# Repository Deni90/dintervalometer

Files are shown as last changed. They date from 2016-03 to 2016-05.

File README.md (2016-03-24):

#Dintervalometer

Intervalometer for DSLR cameras based on Atmega328p and PCD8544 LCD display

##Description

Dintervalometer (Deni's intervalometer) is a custom made intervalometer for DSLR cameras. The main purpose is to enable cameras to shoot time lapses and to allow shutter speed longer than the 30s.

##Features

- Intervalometer
- Bulb mode
- Backlight with variable brightness
- Charging via USB

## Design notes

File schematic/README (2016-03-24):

Schematic and PCB are created with Cadsoft EAGLE

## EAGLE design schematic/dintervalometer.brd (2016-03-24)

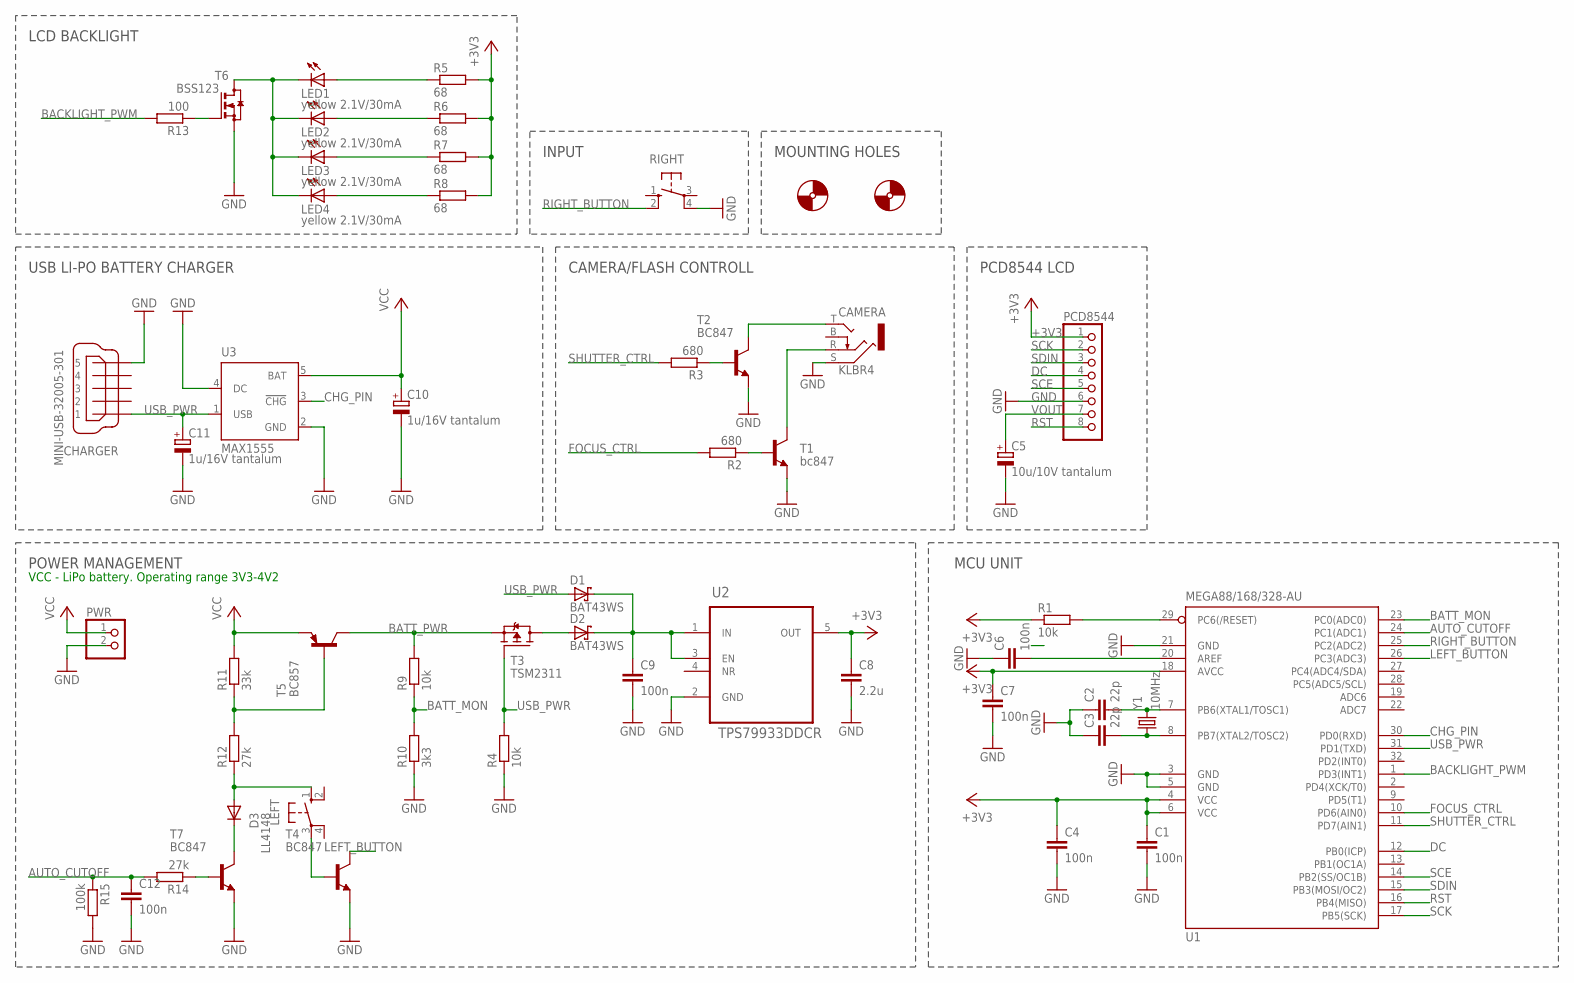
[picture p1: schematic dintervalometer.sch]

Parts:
C1, C4, C6, C7, C9, C12: 100n; C0805
C2, C3: 22p; C0805
C5: 10u/10V tantalum; SMC_A
C8: 2.2u; C0805
C10, C11: 1u/16V tantalum; SMC_A
CAMERA: KLBR4
CHARGER: MINI-USB-32005-301; 32005-301
D1, D2: BAT43WS; SOD323_ST
D3: LL4148; SOD80C
LED1, LED2, LED3, LED4: yellow 2.1V/30mA; CHIP-LED0805
LEFT: 10-XX; B3F-10XX
PCD8544: PINHD-1X8; 1X08
PWR: PINHD-1X2/90; 1X02/90
R1, R4, R9: 10k; M0805
R2, R3: 680; M0805
R5, R6, R7, R8: 68; M0805
R10: 3k3; M0805
R11: 33k; M0805
R12, R14: 27k; M0805
R13: 100; M0805
R15: 100k; M0805
RIGHT: 10-XX; B3F-10XX; MPN B3F-1000
T1: bc847; SOT23-BEC
T2: BC847; SOT23-BEC
T3: TSM2311; SOT23
T4, T7: BC847; SOT23
T5: BC857; SOT23-BEC
T6: BSS123; SOT23
U1: MEGA88/168/328-AU; TQFP32-08
U2: TPS79933DDCR; SOT95P290X145-5N
U3: MAX1555; SOT23-5L
X1, X3: 2.8MM_HOLE
Y1: 10MHz; 5X3.2MM

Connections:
+3V3: C1.1, C4.1, C7.1, C8.1, PCD8544.1, R1.1, R5.2, R6.2, R7.2, R8.2, U1.4 (VCC), U1.6 (VCC), U1.18 (AVCC), U2.5 (OUT)
AUTO_CUTOFF: C12.1, R14.2, R15.1, U1.24 (PC1(ADC1))
BACKLIGHT_PWM: R13.2, U1.1 (PD3(INT1))
BATT_MON: R9.1, R10.2, U1.23 (PC0(ADC0))
BATT_PWR: R9.2, T3.2 (S), T5.C
CHG_PIN: U1.30 (PD0(RXD)), U3.3 (!CHG)
DC: PCD8544.4, U1.12 (PB0(ICP))
FOCUS_CTRL: R2.2, U1.10 (PD6(AIN0))
GND: C1.2, C2.1, C3.1, C4.2, C5.-, C6.1, C7.2, C8.2, C9.2, C10.-, C11.-, C12.2, CAMERA.S, CHARGER.5, PCD8544.6, PWR.2, R4.1, R10.1, R15.2, RIGHT.4 (P1), T1.E, T2.E, T4.2 (E), T6.2 (S), T7.2 (E), U1.3 (GND), U1.5 (GND), U1.21 (GND), U2.2 (GND), U3.2 (GND), U3.4 (DC)
LEFT_BUTTON: T4.3 (C), U1.26 (PC3(ADC3))
unnamed: R1.2, U1.29 (PC6(/RESET))
unnamed: C2.2, U1.7 (PB6(XTAL1/TOSC1)), Y1.3 (2)
unnamed: C3.2, U1.8 (PB7(XTAL2/TOSC2)), Y1.1
unnamed: R3.1, T2.B
unnamed: R11.1, R12.2, T5.B
unnamed: C6.2, U1.20 (AREF)
unnamed: LED1.A, R5.1
unnamed: D3.A, LEFT.1 (S), R12.1
unnamed: D3.C, T7.3 (C)
unnamed: D2.A, T3.3 (D)
unnamed: LEFT.3, T4.1 (B)
unnamed: LED1.C, LED2.C, LED3.C, LED4.C, T6.3 (D)
unnamed: R2.1, T1.B
unnamed: R13.1, T6.1 (G)
unnamed: LED2.A, R6.1
unnamed: LED3.A, R7.1
unnamed: LED4.A, R8.1
unnamed: CAMERA.T, T2.C
unnamed: CAMERA.R, T1.C
unnamed: R14.1, T7.1 (B)
unnamed: C9.1, D1.C, D2.C, U2.1 (IN), U2.3 (EN)
RIGHT_BUTTON: RIGHT.2 (S1), U1.25 (PC2(ADC2))
RST: PCD8544.8, U1.16 (PB4(MISO))
SCE: PCD8544.5, U1.14 (PB2(SS/OC1B))
SCK: PCD8544.2, U1.17 (PB5(SCK))
SDIN: PCD8544.3, U1.15 (PB3(MOSI/OC2))
SHUTTER_CTRL: R3.2, U1.11 (PD7(AIN1))
USB_PWR: C11.+, CHARGER.1, D1.A, R4.2, T3.1 (G), U1.31 (PD1(TXD)), U3.1 (USB)
VCC: C10.+, PWR.1, R11.2, T5.E, U3.5 (BAT)
VOUT: C5.+, PCD8544.7

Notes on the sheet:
VCC - LiPo battery. Operating range 3V3-4V2
USB LI-PO BATTERY CHARGER
LCD BACKLIGHT
CAMERA/FLASH CONTROLL
PCD8544 LCD
MOUNTING HOLES
POWER MANAGEMENT
MCU UNIT
INPUT

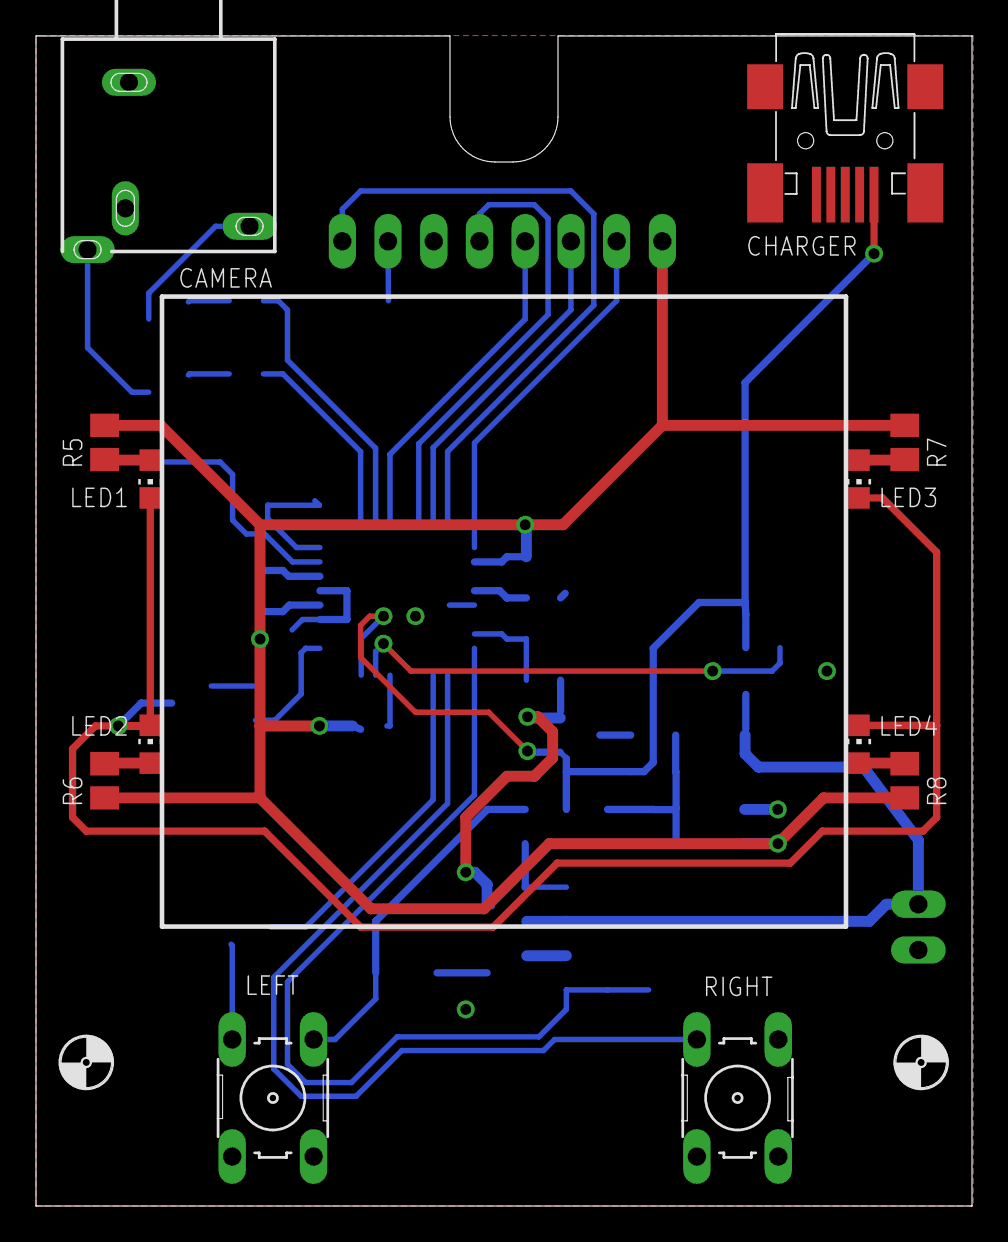
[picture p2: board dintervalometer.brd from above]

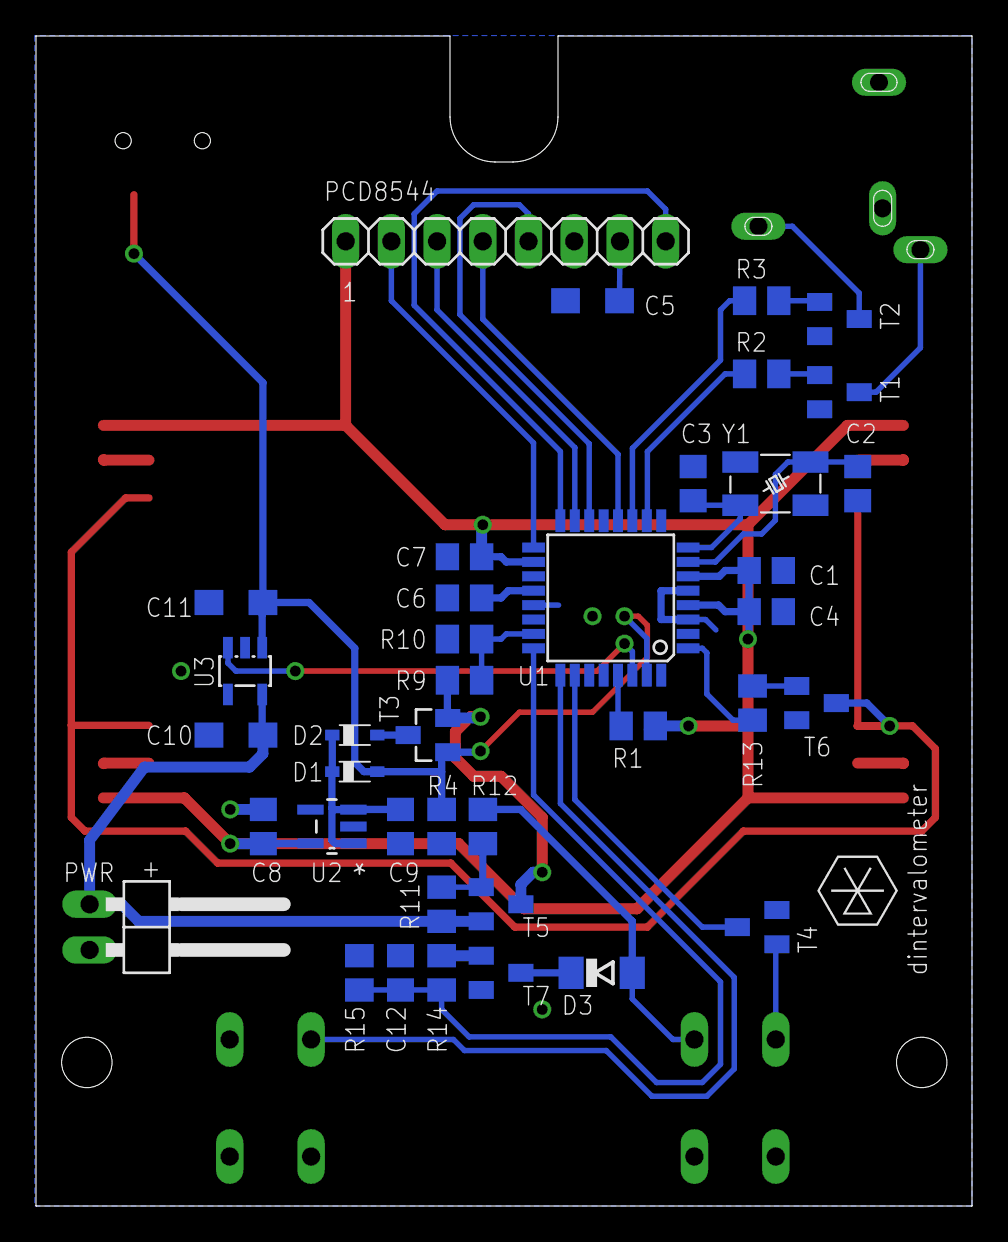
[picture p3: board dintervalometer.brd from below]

Board: 2 copper layers, 52.0 x 65.0 mm, 53 parts (39 on the bottom side), 40 nets.

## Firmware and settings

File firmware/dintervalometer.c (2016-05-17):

/*
 *  dintervalometer.c
 *
 *  "THE DON'T-CARE LICENCE"
 *  I don't care, do whatever you want with this file.
 *
 *  Author: Daniel Knezevic
 *  E-mail: danielknezevic90<at>gmail.com
 */

#include <avr/io.h>
#include <avr/interrupt.h>
#include <avr/eeprom.h>
#include <math.h>

#include "dintervalometer.h"
#include "pcd8544.h"

// String constants and icons stored in flash
const __flash char turn_on_message_str[]
= "Hold buttons for 2s\n     to turn on\n";
const __flash char main_menu_title_str[] = "MAIN MENU\n";
const __flash char intervalometer_menu_title_str[] = "INTERVALOMETER\n";
const __flash char bulb_mode_menu_title_str[] = "BULB MODE\n";
const __flash char settings_menu_title_str[] = "SETTINGS\n";
const __flash char intervalometer_option_str[] = " Intervalometer\n";
const __flash char bulb_mode_option_str[] = " Bulb mode\n";
const __flash char settings_option_str[] = " Settings\n";
const __flash char turn_off_option_str[] = " Turn off\n";
const __flash char delay_str[] = " delay  ";
const __flash char interval_str[] = " period ";
const __flash char shots_str[] = " shots       ";
const __flash char prefocus_str[] = " prefocus    ";
const __flash char start_str[] = " start";
const __flash char duration_str[] = " bulb   ";
const __flash char on_str[] = " on";
const __flash char off_str[] = "off";
const __flash char done_str[] = "Done";
const __flash char help_bar_1_str[] = "down/set        up";
const __flash char help_bar_2_str[] = "down/set  up/back";
const __flash char help_bar_3_str[] = "++/set       --/set";
const __flash char abort_str[] = "/abort";
const __flash char back_str[] = "/back";
const __flash char cleanup_message_str[] = "    Turning off\n    bye, bye :)\n";
const __flash char backlight_str[] = " backlight    ";
const __flash char auto_cutoff_str[] = " auto cutoff ";
const __flash char low_battery_str[] = "Low battery!";
const __flash char charging_str[] = "Charging";
const __flash char full_battery_str[] = "Battery is full";

const __flash char clock_icon[] = {0x00, 0x18, 0x24, 0x42, 0x5e, 0x52, 0x24, 0x18};
const __flash char bulb_icon[] = {0x00, 0x00, 0x02, 0x2d, 0x69, 0x2d, 0x02,
    0x00};
const __flash char settings_icon[] = {0x00, 0x18, 0x18, 0x18, 0x18, 0x3c, 0x24,
    0x24};
const __flash char turn_off_icon[] = {0x00, 0x18, 0x24, 0x40, 0x4e, 0x40, 0x24,
    0x18};
const __flash char delay_icon[] = {0x00, 0x41, 0x63, 0x75, 0x6d, 0x75, 0x63,
    0x41};
const __flash char focus_icon[] = {0x00, 0x63, 0x41, 0x1c, 0x14, 0x1c, 0x41,
    0x63};
const __flash char image_icon[] = {0x00, 0x7f, 0x41, 0x41, 0x4f, 0x49, 0x4a,
    0x7c};
const __flash char start_icon[] = {0x00, 0x00, 0x7f, 0x7f, 0x3e, 0x1c, 0x08,
    0x00};
const __flash char battery_icon_elements[] = {0x1c, 0x63, 0x41, 0x7f};
const __flash char image_icon_top[] = {0x00, 0x00, 0x00, 0x00, 0xfe, 0x02, 0x02,
    0x02, 0x02, 0x7e, 0x42, 0x44, 0x48, 0x50, 0xe0, 0x00, 0x00, 0x00,
    0x00};
const __flash char image_icon_bottom[] = {0x00, 0x00, 0x00, 0x00, 0x3f, 0x20,
    0x20, 0x20, 0x20, 0x20, 0x20, 0x20, 0x20, 0x20, 0x3f, 0x00, 0x00, 0x00,
    0x00};
const __flash char delay_icon_top[] = {0x00, 0x00, 0x00, 0x02, 0x06, 0x0A,
    0x12, 0x62, 0xE2, 0xE2, 0xE2, 0x62, 0x12, 0x0A, 0x06, 0x02, 0x00, 0x00,
    0x00};
const __flash char delay_icon_bottom[] = {0x00, 0x00, 0x00, 0x40, 0x60, 0x70,
    0x78, 0x76, 0x71, 0x73, 0x71, 0x76, 0x78, 0x70, 0x60, 0x40, 0x00, 0x00,
    0x00};
const __flash char bulb_icon_top[] = {0x00, 0x00, 0x00, 0x00, 0x38, 0x44, 0x82,
    0x02, 0x32, 0xD2, 0x32, 0x02, 0x82, 0x44, 0x38, 0x00, 0x00, 0x00, 0x00};
const __flash char bulb_icon_bottom[] = {0x00, 0x00, 0x00, 0x00, 0x00, 0x00,
    0x01, 0x0E, 0x38, 0x7F, 0x38, 0x0E, 0x01, 0x00, 0x00, 0x00, 0x00, 0x00,
    0x00};
const __flash char battery_icon[] = {0x1c, 0x36, 0x22, 0x22, 0x22, 0x3e, 0x3e,
    0x3e};
const __flash char battery_tray_icon[] = {0x0e, 0x1f, 0x11, 0x11, 0x11, 0x11, 0x11,
    0x11, 0x11, 0x11, 0x11, 0x11, 0x1f};
const __flash char backlight_icon[] = {0x08, 0x2a, 0x1c, 0x7f, 0x1c, 0x2a, 0x08,
    0x00};

// RAM varibles used for measuring/counting time for various actions
volatile unsigned int clock;                    // used for global timer
volatile unsigned int blink_timer = 0;         //used for blinking in menus
volatile unsigned int button_hold_timer = 0;  // counter for press/hold decision
volatile unsigned int unlock_timer = 0;         // timer to unlock the device
volatile unsigned int timeout_timer = 0; // timer to turn off the device on startup when there is no input from the user
volatile unsigned int delay_timer = 0; // used for interrupt based delay function
volatile unsigned int debounce_timer = 0;       // used for button debunce
volatile unsigned int backlight_timer = 0; // backlight is on until the value reaches 0
volatile unsigned int battery_check_timer = 0;  // timer for battery management

// RAM variables used to store information related to states of the buttons
volatile uint8_t button_press = 0x00;
volatile uint8_t button_hold = 0x00;
volatile uint8_t last_button_state = 0x00;

// Settings with initial values stored in eeprom
settings_t EEMEM settings_data_backup = { 0, MIN_BATTERY_VOLTAGE };

// Global variables
state_t cur_state = INIT;
uint8_t selected_menu_item = 0;
uint8_t is_prop_selected = 0;
uint8_t is_blinking = 0;
intervalometer_t intervalometer_data = { 0, 0, 0, 0 };
intervalometer_t intervalometer_temp_data = { 0, 0, 0, 0 };
uint8_t intervalometer_pre_start = FALSE;
uint16_t remaining_time = 0; // seconds
uint8_t update_image_icon = 0;
bulb_mode_t bulb_mode_data = { 0, 0 };
bulb_mode_t bulb_mode_temp_data = { 0, 0 };
uint8_t bulb_mode_pre_start = FALSE;
uint8_t number_part = 0;
settings_t settings_data;
uint16_t battery_voltage = 0;

// State functions
state_t STATE_init(void);
state_t STATE_main_menu(void);
state_t STATE_intervalometer_menu(void);
state_t STATE_bulb_mode_menu(void);
state_t STATE_settings_menu(void);
state_t STATE_intervalometer(void);
state_t STATE_bulb_mode(void);
state_t STATE_turn_off(void);

// state functions must be in same order as states in state_t enum (look in dintervalometer.h)
state_func_t* const state_table[NUM_OF_STATES] = { STATE_main_menu,
        STATE_intervalometer_menu, STATE_bulb_mode_menu, STATE_settings_menu,
        STATE_turn_off, STATE_intervalometer, STATE_bulb_mode, STATE_init };

state_t STATE_run_state(state_t cur_state) {
    return state_table[cur_state]();
}

// Misc
/*
 * Initializes timer1
 */
void TIMER_init(void);

/*
 * Interrupt based delay function 1-65536ms (65sec max)
 */
void TIMER_delay_ms(uint16_t _mS);

/*
 * Initializes ADC on ADC0(PC0) for battery voltage monitoring
 */
void BATTERY_init_adc(void);

/*
 * Reads battery voltage by using ADC.
 * return value: measured value in mV
 */
uint16_t BATTERY_read_voltage(void);

/*
 * Periodically measures battery voltage and if the voltage is under the
 * margin notifies the user with some message and turns off the device
 */
void BATTERY_monitor(void);

/*
 * Initializes timer2 for PWM on OC2B(PD3), PWM frewuency should be few kHz
 */
void BACKLIGHT_init_pwm(void);

/*
 * Updates backlight status. It will be turned on if brightness > 0
 */
void BACKLIGHT_update(uint8_t brightness);

/*
 * Basic GPIO initialization
 */
void GPIO_init(void);

/*
 * Prints hh:mm:ss time format from seconds
 */
void LCD_print_time(uint16_t _value, uint8_t size);

/*
 * Draws a scroll bar on LCD based on number of items and on currently
 * selected item
 */
void LCD_update_scroll_bar(uint8_t selected_item, uint8_t total_items);

/*
 * Draws a battery icon on top right corner of the LCD based on the measured
 * battery voltage
 */
void LCD_update_battery_icon(uint16_t voltage);

/*
 * Shows low battery notification
 */
void LCD_show_low_battery_alert(void);

/*
 * Timer1 "Compare Match" ISR
 */
ISR(TIMER1_COMPA_vect, ISR_NOBLOCK) {
    clock++;
    blink_timer++;
    delay_timer++;
    debounce_timer++;
    battery_check_timer++;
    if (button_hold_timer)
        button_hold_timer--;   // to detect button holds, we shouldn't overflow!
    if (unlock_timer)
        unlock_timer--;         // to unlock the device, we shouldn't overflow!
    if (timeout_timer)
        timeout_timer--;       // to turn off the device, we shouldn't overflow!
    if (backlight_timer)
        backlight_timer--;
    else
        OCR2B = 0; // turn off the backlight
}

/*
 * Interrupt based button sensing
 * Code borrowed and modified from:
 * http://www.elektronika.ba/789/reverse-geocaching-geogame-v1/
 */
ISR(PCINT1_vect, ISR_NOBLOCK) {
    PCICR &= ~(1 << PCIE1);     // ..disable interrupts for the entire section

    /* up/set button handling part */
    if (!(LEFT_BUTTON_PIN & (1 << LEFT_BUTTON_IO))) {   // if is button pressed
        // see if it wasn't pressed at all
        if (!(last_button_state & (1 << LEFT_BUTTON_IO))) {
            TIMER_delay_ms(DEBOUNCE_INTERVAL);                       // debounce
            // if it is still not VCC after DEBOUNCE_INTERVAL, this was an error
            if ((LEFT_BUTTON_PIN & (1 << LEFT_BUTTON_IO))) {
                PCICR |= (1 << PCIE1); // ..re-enable interrupts for the entire section
                return;
            }
            last_button_state |= (1 << LEFT_BUTTON_IO);
            button_hold_timer = BUTTON_HOLD_INTERVAL; // load for hold detection
            while (button_hold_timer > 0) {
                // if button released in meantime
                if ((LEFT_BUTTON_PIN & (1 << LEFT_BUTTON_IO))) {
                    button_press = (1 << LEFT_BUTTON_IO); // this was just a press!
                    PCICR |= (1 << PCIE1); // ..re-enable interrupts for the entire section
                    return;
                }
            }
            // if we get to this line, the button is still pressed, so "it is held"
            button_hold = (1 << LEFT_BUTTON_IO);
        }
    } else {
        last_button_state &= ~(1 << LEFT_BUTTON_IO);
    }

    /* down/back button handling part */
    if (!(RIGHT_BUTTON_PIN & (1 << RIGHT_BUTTON_IO))) { // if button is pressed
        // see if it wasn't pressed at all
        if (!(last_button_state & (1 << RIGHT_BUTTON_IO))) {
            TIMER_delay_ms(DEBOUNCE_INTERVAL);                       // debounce
            // if it is still not VCC after DEBOUNCE_INTERVAL, this was an error
            if ((RIGHT_BUTTON_PIN & (1 << RIGHT_BUTTON_IO))) {
                PCICR |= (1 << PCIE1); // ..re-enable interrupts for the entire section
                return;
            }
            last_button_state |= (1 << RIGHT_BUTTON_IO);
            button_hold_timer = BUTTON_HOLD_INTERVAL; // load for hold detection
            while (button_hold_timer > 0) {
                // if button released in meantime
                if ((RIGHT_BUTTON_PIN & (1 << RIGHT_BUTTON_IO))) {
                    button_press = (1 << RIGHT_BUTTON_IO); // this was just a press!
                    PCICR |= (1 << PCIE1); // ..re-enable interrupts for the entire section
                    return;
                }
            }
            // if we get to this line, the button is still pressed, so "it is held"
            button_hold = (1 << RIGHT_BUTTON_IO);
        }
    } else {
        last_button_state &= ~(1 << RIGHT_BUTTON_IO);
    }

    PCICR |= (1 << PCIE1);  // ..re-enable interrupts for the entire section
}

int main(void) {
    TIMER_init();
    BATTERY_init_adc();
    BACKLIGHT_init_pwm();
    GPIO_init();
    // Enable Global Interrupts
    sei();
    LCD_init();

    // restore settings from eeprom
    eeprom_read_block(&settings_data, &settings_data_backup,
            sizeof(settings_t));

    while (1) {
        cur_state = STATE_run_state(cur_state);   //start the state machine
    }   // while
    return 0;
}

state_t STATE_init(void) {
    state_t next_state = cur_state;
    PCICR &= ~(1 << PCIE1); // Disable PIN Change Interrupt 1 - This disables interrupts on pins PCINT14...8 see p73 of datasheet

    BACKLIGHT_update(settings_data.backlight_intensity);

    LCD_clear();

    // First check are the device powered with USB (Charging the battery)
    if (USB_PWR_PIN & (1 << USB_PWR_IO)) {
        if (CHG_PIN & (1 << CHG_IO)) {
            // charging in progress
            LCD_goto(25, 2);
            LCD_puts(charging_str, LCD_TYP_NORM);
        }
        // block until the battery is full -> CHG = 0
        while (CHG_PIN & (1 << CHG_IO))
            ;
        // battery is full
        LCD_clear();
        LCD_goto(12, 2);
        LCD_puts(full_battery_str, LCD_TYP_NORM);

    }
    // block until the USB is connected
    while (USB_PWR_PIN & (1 << USB_PWR_IO))
        ;

    battery_voltage = BATTERY_read_voltage();
    if (battery_voltage < settings_data.battery_auto_cutoff) {
        LCD_show_low_battery_alert();
        STATE_turn_off();
    }
    LCD_update_battery_icon(battery_voltage);
    LCD_goto(0, 2);
    // show help message to turn on the device
    LCD_puts(turn_on_message_str, LCD_TYP_NORM);
    timeout_timer = TIMEOUT_INTERVAL;   // start timer
    AUTO_CUTOFF_PORT |= (1 << AUTO_CUTOFF_IO);  // pull up the port

    while (1) {
        // if it reaches timeout turn off the device
        if (timeout_timer == 0) {
            next_state = OFF;
            break;
        }
        // check the buttons. If the buttons are held until the UNLOCK_INTERVAL unlock the device.
        if (!(LEFT_BUTTON_PIN & (1 << LEFT_BUTTON_IO))
                && !(RIGHT_BUTTON_PIN & (1 << RIGHT_BUTTON_IO))) {
            TIMER_delay_ms(DEBOUNCE_INTERVAL);    // debounce
            // if some of the buttons are released in the meantime, turn off the device
            if ((LEFT_BUTTON_PIN & (1 << LEFT_BUTTON_IO))
                    || (RIGHT_BUTTON_PIN & (1 << RIGHT_BUTTON_IO))) {
                next_state = OFF;
                break;
            }
            last_button_state |= (1 << LEFT_BUTTON_IO) | (1 << RIGHT_BUTTON_IO);
            uint8_t i;
            // Show initial progress bar and battery icon
            LCD_clear();
            LCD_update_battery_icon(battery_voltage);
            LCD_goto(10, 2);
            for (i = 0; i < 64; i++) {
                if (i == 0 || i == 63)
                    LCD_writeData(0xff);
                else
                    LCD_writeData(0x81);
            }
            // prepare for successful unlock
            next_state = MAIN_MENU;
            selected_menu_item = 0;
            // start unlock_timer
            unlock_timer = UNLOCK_INTERVAL;
            while (unlock_timer > 0) {
                // Update progress bar
                LCD_goto(10, 2);
                for (i = 0; i < 64; i++) {
                    if (i < 64 - unlock_timer / 31 || i == 63)
                        LCD_writeData(0xff);
                    else
                        LCD_writeData(0x81);
                }
                // check if the buttons are released in the meantime, if yes turn off the device
                if ((LEFT_BUTTON_PIN & (1 << LEFT_BUTTON_IO))
                        || (RIGHT_BUTTON_PIN & (1 << RIGHT_BUTTON_IO))) {
                    last_button_state &= ~(1 << LEFT_BUTTON_IO)
                            & ~(1 << RIGHT_BUTTON_IO);
                    next_state = OFF;
                    break;
                }
            }
            break;
        }
    }
    return next_state;
}

state_t STATE_main_menu(void) {
    uint8_t menu_size;
    state_t next_state = cur_state;
    PCICR &= ~(1 << PCIE1); // Disable PIN Change Interrupt 1 - This disables Interrupt 1 - This enables interrupts on pins PCINT14...8 see p73 of datasheet
    // main menu
    LCD_clear();
    LCD_update_battery_icon(battery_voltage);
    menu_size = 4;
    // menu title
    LCD_puts(main_menu_title_str, LCD_TYP_UP2);
    // intervalometer menu item (icon + name)
    LCD_putCustomChar(clock_icon, ICON_WIDTH,
            (selected_menu_item == 0) ? LCD_TYP_INV : LCD_TYP_NORM);
    LCD_puts(intervalometer_option_str,
            (selected_menu_item == 0) ? LCD_TYP_INV : LCD_TYP_NORM);
    // bulb mode menu item  (icon + name)
    LCD_putCustomChar(bulb_icon, ICON_WIDTH,
            (selected_menu_item == 1) ? LCD_TYP_INV : LCD_TYP_NORM);
    LCD_puts(bulb_mode_option_str,
            (selected_menu_item == 1) ? LCD_TYP_INV : LCD_TYP_NORM);
    // settings menu item  (icon + name)
    LCD_putCustomChar(settings_icon, ICON_WIDTH,
            (selected_menu_item == 2) ? LCD_TYP_INV : LCD_TYP_NORM);
    LCD_puts(settings_option_str,
            (selected_menu_item == 2) ? LCD_TYP_INV : LCD_TYP_NORM);
    LCD_putCustomChar(turn_off_icon, ICON_WIDTH,
            (selected_menu_item == 3) ? LCD_TYP_INV : LCD_TYP_NORM);
    LCD_puts(turn_off_option_str,
            (selected_menu_item == 3) ? LCD_TYP_INV : LCD_TYP_NORM);
    // help bar on the bottom
    LCD_goto(0, 5);
    LCD_puts(help_bar_1_str, LCD_TYP_NORM);
    // draw scroll bar
    LCD_update_scroll_bar(selected_menu_item, menu_size);

    PCICR |= (1 << PCIE1); // Enable PIN Change Interrupt 1 - This enables interrupts on pins PCINT14...8 see p73 of datasheet
    // wait button press or hold
    while (!(button_press | button_hold)) {
        // periodically check the battery status
        BATTERY_monitor();
    }

    // turn on the backlight (if enabled) when some button is pressed/held
    BACKLIGHT_update(settings_data.backlight_intensity);

    if (button_press & (1 << LEFT_BUTTON_IO)) {
        button_press &= ~(1 << LEFT_BUTTON_IO); // button press handled
        button_hold &= ~(1 << LEFT_BUTTON_IO); // also clear the hold flag if any...
        selected_menu_item++;
        selected_menu_item %= menu_size;
    } else if (button_press & (1 << RIGHT_BUTTON_IO)) {
        button_press &= ~(1 << RIGHT_BUTTON_IO); // button press handled
        button_hold &= ~(1 << RIGHT_BUTTON_IO); // also clear the hold flag if any...
        if (selected_menu_item)
            selected_menu_item--;
        else
            selected_menu_item = menu_size - 1;
    } else if (button_hold & (1 << LEFT_BUTTON_IO)) {
        button_hold &= ~(1 << LEFT_BUTTON_IO);  // button hold handled
        button_press &= ~(1 << LEFT_BUTTON_IO); // also clear the press flag if any...
        next_state = selected_menu_item + 1; // next state is a selected submenu item
        selected_menu_item = 0;
    } else if ((button_press & (1 << RIGHT_BUTTON_IO))
            || (button_hold & (1 << RIGHT_BUTTON_IO))) {
        // clear the press/hold flag
        button_hold &= ~(1 << RIGHT_BUTTON_IO);
        button_press &= ~(1 << RIGHT_BUTTON_IO);
    }
    return next_state;
}
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

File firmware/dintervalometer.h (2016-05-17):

/*
 *  dintervalometer.h
 *
 *  "THE DON'T-CARE LICENCE"
 *  I don't care, do whatever you want with this file.
 *
 *  Author: Daniel Knezevic
 *  E-mail: danielknezevic90<at>gmail.com
 */

#ifndef DINTERVALOMETER_H_
#define DINTERVALOMETER_H_

#define TRUE                    1
#define FALSE                   0

#define ONE_SECOND              1000    // milliseconds

#define BUTTON_HOLD_INTERVAL    1000    // miliseconds to pronounce button as held rather than pressed
#define UNLOCK_INTERVAL         2000    // milliseconds
#define TIMEOUT_INTERVAL        2000    // milliseconds
#define DEBOUNCE_INTERVAL       50      // milliseconds

#define LEFT_BUTTON_DDR         DDRC
#define LEFT_BUTTON_PIN         PINC
#define LEFT_BUTTON_PORT        PORTC
#define LEFT_BUTTON_IO          PC3

#define RIGHT_BUTTON_DDR        DDRC
#define RIGHT_BUTTON_PIN        PINC
#define RIGHT_BUTTON_PORT       PORTC
#define RIGHT_BUTTON_IO         PC2

#define AUTO_CUTOFF_DDR         DDRC
#define AUTO_CUTOFF_PIN         PINC
#define AUTO_CUTOFF_PORT        PORTC
#define AUTO_CUTOFF_IO          PC1

#define SHUTTER_DDR             DDRD
#define SHUTTER_PIN             PIND
#define SHUTTER_PORT            PORTD
#define SHUTTER_IO              PD7

#define FOCUS_DDR               DDRD
#define FOCUS_PIN               PIND
#define FOCUS_PORT              PORTD
#define FOCUS_IO                PD6

#define CHG_DDR                 DDRD
#define CHG_PIN                 PIND
#define CHG_PORT                PORTD
#define CHG_IO                  PD0

#define USB_PWR_DDR             DDRD
#define USB_PWR_PIN             PIND
#define USB_PWR_PORT            PORTD
#define USB_PWR_IO              PD1

#define BACKLIGHT_DDR           DDRD
#define BACKLIGHT_PIN           PIND
#define BACKLIGHT_PORT          PORTD
#define BACKLIGHT_IO            PD3
#define BACKLIGHT_DURATION      10000   // millisecond

#define BLINK_PERIOD           1000     // millisecons
#define ICON_WIDTH              8

#define MAX_BATTERY_VOLTAGE     4200    // mV
#define MIN_BATTERY_VOLTAGE     3600    // mV
#define BATTERY_MONITOR_PERIOD  60000   // milliseconds

#define PN_JUNCTION             600     // mV

#define BACKLIGHT_INTENSITY     63

typedef enum state_e {
    MAIN_MENU = 0,
    INTERVALOMETER_MENU,
    BULB_MODE_MENU,
    SETTINGS,
    OFF,
    INTERVALOMETER,
    BULB_MODE,
    INIT,
    NUM_OF_STATES
} state_t;

typedef state_t state_func_t(void);

typedef struct intervalometer_s {
    uint16_t delay;
    uint16_t period;
    uint16_t shots;
    uint8_t prefocus;
} intervalometer_t;

typedef struct bulb_mode_s {
    uint16_t delay;
    uint16_t duration;
} bulb_mode_t;

typedef struct settings_s {
    uint8_t backlight_intensity;
    uint16_t battery_auto_cutoff;   //mV
} settings_t;

#endif /* DINTERVALOMETER_H_ */

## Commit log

2016-03-31 Code cleanup
    Bugfix, removed unused enum "SENSOR" from states
    [dintervalometer.h]
2016-04-07 Simplified backlight and changed battery monitor
2016-05-17 Fixed reading battery voltage
    [dintervalometer.c, dintervalometer.h]
